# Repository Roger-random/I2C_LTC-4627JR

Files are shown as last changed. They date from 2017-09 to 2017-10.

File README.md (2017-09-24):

# I2C control of a Lite-On LTC4627-JR (4-digit 7-segment LED)

The goal of this project is to create a small module that interfaces a 4-digit 7-segment LED to an I2C bus.

The original motivation is to allow a Raspberry Pi to display a few hexadecimal numbers with minimal overhead. Send a few bytes over I2C and this module will handle the rest.

Parts:

* The LED unit is the Lite-On LTC4627-JR. 
It has some features in addition to the standard 4-digit 7-segment design:
1. This is actually an 8-segment LED because of the 7-segments for numerals plus a LED for the optional decimal point.
2. This is actually a 5-digit display because of a few additional symbols on the surface. It appears to have been designed for a clock display so there are three additional LEDs controlled as a "fifth digit":  Two LEDs for displaying the ":" in 12:00 and a third probably to designate AM/PM.

* The brains of this operation will be a PIC 16F18345

* Current-limiting resistors * 8, one for each of the segments.

* NPN transistors * 5, one for each of the digits.

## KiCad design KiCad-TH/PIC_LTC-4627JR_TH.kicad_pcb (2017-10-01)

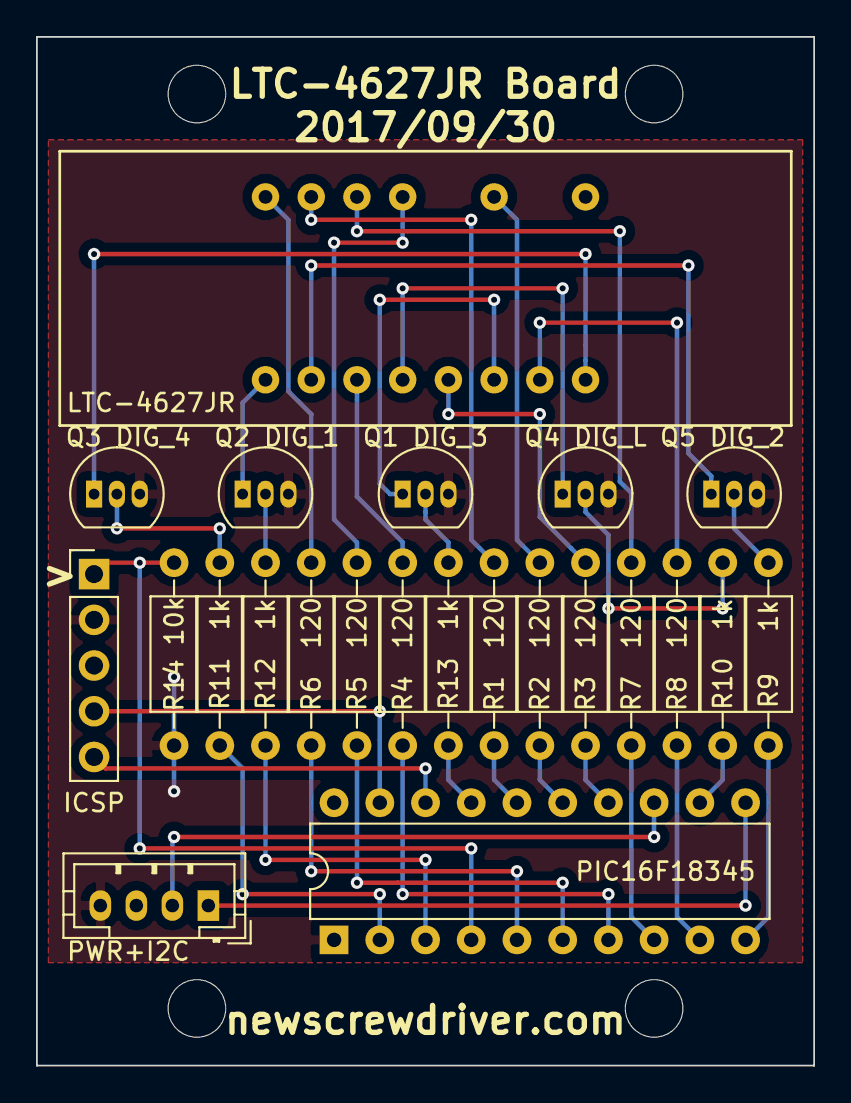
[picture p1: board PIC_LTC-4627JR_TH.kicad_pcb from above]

Board: 2 copper layers, 43.2 x 57.2 mm, 27 parts (0 on the bottom side), 38 nets.

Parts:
H1, H2, H3, H4: MountingHole_3.2mm_M3
ICSP: Conn_01x05_Male; Pin_Header_Straight_1x05_Pitch2.54mm
LTC-4627JR: LTC-4627JR
PIC16F18345: PIC16F18344-P; DIP-20_W7.62mm
PWR+I2C: Conn_01x04; JST_PH_B4B-PH-K_04x2.00mm_Straight
Q1 DIG_3, Q2 DIG_1, Q3 DIG_4, Q4 DIG_L, Q5 DIG_2: Q_NPN_EBC; TO-92_Inline_Narrow_Oval
R1  120, R2  120, R3  120, R4  120, R5  120, R6  120, R7  120, R8  120: 120; R_Axial_DIN0207_L6.3mm_D2.5mm_P10.16mm_Horizontal
R9   1k, R10  1k, R11  1k, R12  1k, R13  1k: 1k; R_Axial_DIN0207_L6.3mm_D2.5mm_P10.16mm_Horizontal
R14 10k: 10k; R_Axial_DIN0207_L6.3mm_D2.5mm_P10.16mm_Horizontal

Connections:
/DIG_1: LTC-4627JR.1, Q2 DIG_1.1
/DIG_2: LTC-4627JR.2, Q5 DIG_2.1
/DIG_3: LTC-4627JR.6, Q1 DIG_3.1
/DIG_4: LTC-4627JR.8, Q3 DIG_4.1
/DIG_L: LTC-4627JR.4, Q4 DIG_L.1
/I2CCL: PIC16F18345.11, PWR+I2C.1
/I2CDA: PIC16F18345.13, PWR+I2C.2
/ICSPCLK: ICSP.5, PIC16F18345.18
/ICSPDAT: ICSP.4, PIC16F18345.19
/VPP: ICSP.1, PIC16F18345.4, R14 10k.1
GND: ICSP.3, PIC16F18345.20, PWR+I2C.3
unnamed: LTC-4627JR.3, R4 120.1
unnamed: LTC-4627JR.5, R3 120.1
unnamed: LTC-4627JR.7, R8 120.1
unnamed: LTC-4627JR.11, R2 120.1
unnamed: LTC-4627JR.13, R5 120.1
unnamed: LTC-4627JR.14, R7 120.1
unnamed: LTC-4627JR.15, R1 120.1
unnamed: LTC-4627JR.16, R6 120.1
unnamed: Q1 DIG_3.2, R13 1k.1
unnamed: Q2 DIG_1.2, R12 1k.1
unnamed: Q3 DIG_4.2, R11 1k.1
unnamed: Q4 DIG_L.2, R10 1k.1
unnamed: Q5 DIG_2.2, R9 1k.1
unnamed: PIC16F18345.16, R1 120.2
unnamed: PIC16F18345.15, R2 120.2
unnamed: PIC16F18345.14, R3 120.2
unnamed: PIC16F18345.7, R4 120.2
unnamed: PIC16F18345.6, R5 120.2
unnamed: PIC16F18345.5, R6 120.2
unnamed: PIC16F18345.8, R7 120.2
unnamed: PIC16F18345.9, R8 120.2
unnamed: PIC16F18345.10, R9 1k.2
unnamed: PIC16F18345.12, R10 1k.2
unnamed: PIC16F18345.2, R11 1k.2
unnamed: PIC16F18345.3, R12 1k.2
unnamed: PIC16F18345.17, R13 1k.2
VCC: ICSP.2, PIC16F18345.1, PWR+I2C.4, Q1 DIG_3.3, Q2 DIG_1.3, Q3 DIG_4.3, Q4 DIG_L.3, Q5 DIG_2.3, R14 10k.2

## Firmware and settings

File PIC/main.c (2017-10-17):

/**
  Generated Main Source File

  Company:
    Microchip Technology Inc.

  File Name:
    main.c

  Summary:
    This is the main file generated using PIC10 / PIC12 / PIC16 / PIC18 MCUs 

  Description:
    This header file provides implementations for driver APIs for all modules selected in the GUI.
    Generation Information :
        Product Revision  :  PIC10 / PIC12 / PIC16 / PIC18 MCUs  - 1.45
        Device            :  PIC16F18345
        Driver Version    :  2.00
    The generated drivers are tested against the following:
        Compiler          :  XC8 1.35
        MPLAB             :  MPLAB X 3.40
*/

/*
    (c) 2016 Microchip Technology Inc. and its subsidiaries. You may use this
    software and any derivatives exclusively with Microchip products.

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
    IN NO EVENT WILL MICROCHIP BE LIABLE FOR ANY INDIRECT, SPECIAL, PUNITIVE,
    INCIDENTAL OR CONSEQUENTIAL LOSS, DAMAGE, COST OR EXPENSE OF ANY KIND
    WHATSOEVER RELATED TO THE SOFTWARE, HOWEVER CAUSED, EVEN IF MICROCHIP HAS
    BEEN ADVISED OF THE POSSIBILITY OR THE DAMAGES ARE FORESEEABLE. TO THE
    FULLEST EXTENT ALLOWED BY LAW, MICROCHIP'S TOTAL LIABILITY ON ALL CLAIMS IN
    ANY WAY RELATED TO THIS SOFTWARE WILL NOT EXCEED THE AMOUNT OF FEES, IF ANY,
    THAT YOU HAVE PAID DIRECTLY TO MICROCHIP FOR THIS SOFTWARE.

    MICROCHIP PROVIDES THIS SOFTWARE CONDITIONALLY UPON YOUR ACCEPTANCE OF THESE
    TERMS.
*/

#include "mcc_generated_files/mcc.h"

// Local variables

// Data received via I2C for what we should display
static uint8_t displayBuffer[DISPLAY_BUFFER_SIZE];

// Bit pattern to display each of the digits.
static uint8_t digitPatterns[] = {0xFF, 0xFF, 0xFF, 0xFF, 0xFF};

// Lookup table to translate numbers/letters into LED bit patterns
//
// The bit pattern mimics the one defined in the MAX7219 driver chip
//
//        A
//      -----
//     |     |
//   F |     | B            Byte
//     |  G  |              MSB                LSB
//      -----               7  6  5  4  3  2  1  0
//     |     |              DP A  B  C  D  E  F  G
//   E |     | C
//     |     |
//      -----
//        D       DP
//
// Since the LTC-4627JR LED module is a common-anode design, each of the bit
// controlling the segment is a cathode. Meaning the LED energizes when the
// bit is set to zero.
//  
//   0xFF = everything is dark.       0x00 = all segments are illuminated.

// Given a value in 0x0 - 0xF, decode into the bit pattern used to display that
// digit.
uint8_t decodeHex(uint8_t value)
{
    // 0000 0      0100 4      1000 8      1100 C
    // 0001 1      0101 5      1001 9      1101 D
    // 0010 2      0110 6      1010 A      1110 E
    // 0011 3      0111 7      1011 B      1111 F
    static uint8_t decoded[] = {
        0x81, // 0 = 1000 0001 
        0xCF, // 1 = 1100 1111
        0x92, // 2 = 1001 0010
        0x86, // 3 = 1000 0110
        0xCC, // 4 = 1100 1100
        0xA4, // 5 = 1010 0100
        0xA0, // 6 = 1010 0000
        0x8F, // 7 = 1000 1111
        0x80, // 8 = 1000 0000
        0x8C, // 9 = 1000 1100
        0x88, // A = 1000 1000
        0xE0, // B = 1110 0000
        0xB1, // C = 1011 0001
        0xC2, // D = 1100 0010
        0xB0, // E = 1011 0000
        0xB8  // F = 1011 1000
    };
    
    if (value <= 0xF)
    {
        return decoded[value];
    }
    else
    {
        return 0xFF; // Active low means 0xFF is dark.
    }
}

// Given a value in ASCII 0x00 - 0x7F, decode into the bit pattern used to
// display that ASCII character. Given the limited nature of a 7-segment
// LED only a few will return actual bit patterns. Most of them will return
// the pattern for space (0xFF))
uint8_t decodeASCII(uint8_t asciiValue)
{
    // Range of numbers 0-9
    if (asciiValue >= 0x30 && asciiValue <= 0x39)
    {
        // Subtracting the ascii value of '0' returns hex index for decodeHex
        return decodeHex(asciiValue - 0x30);
    }
    // Range of uppercase letters A-F
    if (asciiValue >= 0x41 && asciiValue <= 0x46)
    {
        // Subtracting the ascii of 'A' plus 10 returns hex index for decodeHex.
        return decodeHex(asciiValue - 0x41 + 10);
    }
    // Range of lowercase letters A-F
    if (asciiValue >= 0x61 && asciiValue <= 0x66)
    {
        // Subtracting the ascii of 'a' plus 10 returns hex index for decodeHex.
        return decodeHex(asciiValue - 0x61 + 10);
    }
    return 0xFF; // Blank space
}

// Called by a timer ISR to illuminate another digit in the display.
void nextDigit(void)
{
    static uint8_t digit = 0;

    switch(digit)
    {
        case 0:
            DIG_L_SetLow();
            LATC = digitPatterns[0];
            DIG_1_SetHigh();
            digit = 1;
            break;
        case 1:
            DIG_1_SetLow();
            LATC = digitPatterns[1];
            DIG_2_SetHigh();
            digit = 2;
            break;
        case 2:
            DIG_2_SetLow();
            LATC = digitPatterns[2];
            DIG_3_SetHigh();
            digit = 3;
            break;
        case 3:
            DIG_3_SetLow();
            LATC = digitPatterns[3];
            DIG_4_SetHigh();
            digit = 4;
            break;
        case 4:
            DIG_4_SetLow();
            LATC = digitPatterns[4];
            DIG_L_SetHigh();
            digit = 0;
            break;
        default:
            DIG_1_SetLow();
            DIG_2_SetLow();
            DIG_3_SetLow();
            DIG_4_SetLow();
            DIG_L_SetLow();
            LATC = 0x0;
            digit = 0;
            break;
    }
}

/*
                         Main application
 */
void main(void)
{
    size_t dataIndex = 0;

    // initialize the device
    SYSTEM_Initialize();

    // When using interrupts, you need to set the Global and Peripheral Interrupt Enable bits
    // Use the following macros to:

    // Enable the Global Interrupts
    INTERRUPT_GlobalInterruptEnable();

    // Enable the Peripheral Interrupts
    INTERRUPT_PeripheralInterruptEnable();

    // Disable the Global Interrupts
    //INTERRUPT_GlobalInterruptDisable();

    // Disable the Peripheral Interrupts
    //INTERRUPT_PeripheralInterruptDisable();

    digitPatterns[0] = 0xC9; // Nonstandard "II" in a single digit
    digitPatterns[1] = decodeASCII('C');
    digitPatterns[2] = decodeASCII('4');
    digitPatterns[3] = decodeASCII('2');
    digitPatterns[4] = 0xFF;
    
    while (1)
    {
        if(I2C1_DataAvailable())
        {
            I2C1_CopyDisplayBuffer(displayBuffer);

            // Digit 5 are dark unless specifically illuminated
            digitPatterns[4] = 0xFF;

            dataIndex = 0;
            for (size_t digit = 0; digit < 4; digit++)
            {
                digitPatterns[digit] = decodeASCII(displayBuffer[dataIndex]);
                dataIndex++;
                if (displayBuffer[dataIndex]=='.')
                {
                    // Light up the decimal point
                    digitPatterns[digit] = digitPatterns[digit] & 0x7F;
                    dataIndex++;
                }
                if (digit==1 && displayBuffer[dataIndex]==':')
                {
                    // Light up the colon
                    digitPatterns[4] = digitPatterns[4] & 0x9F;
                    dataIndex++;
                }
                if (digit==2 && (displayBuffer[dataIndex]=='\'') || (displayBuffer[dataIndex]=='`'))
                {
                    // Light up the upper dot thingie
                    digitPatterns[4] = digitPatterns[4] & 0xEF;
                    dataIndex++;
                }
            }
        }
    }
}
/**
 End of File
*/

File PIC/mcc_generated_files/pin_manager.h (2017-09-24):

/**
  @Generated Pin Manager Header File

  @Company:
    Microchip Technology Inc.

  @File Name:
    pin_manager.h

  @Summary:
    This is the Pin Manager file generated using MPLAB(c) Code Configurator

  @Description:
    This header file provides implementations for pin APIs for all pins selected in the GUI.
    Generation Information :
        Product Revision  :  MPLAB(c) Code Configurator - 4.26
        Device            :  PIC16F18345
        Version           :  1.01
    The generated drivers are tested against the following:
        Compiler          :  XC8 1.35
        MPLAB             :  MPLAB X 3.40

    Copyright (c) 2013 - 2015 released Microchip Technology Inc.  All rights reserved.

    Microchip licenses to you the right to use, modify, copy and distribute
    Software only when embedded on a Microchip microcontroller or digital signal
    controller that is integrated into your product or third party product
    (pursuant to the sublicense terms in the accompanying license agreement).

    You should refer to the license agreement accompanying this Software for
    additional information regarding your rights and obligations.

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
*/


#ifndef PIN_MANAGER_H
#define PIN_MANAGER_H

#define INPUT   1
#define OUTPUT  0

#define HIGH    1
#define LOW     0

#define ANALOG      1
#define DIGITAL     0

#define PULL_UP_ENABLED      1
#define PULL_UP_DISABLED     0

// get/set DIG_3 aliases
#define DIG_3_TRIS               TRISAbits.TRISA2
#define DIG_3_LAT                LATAbits.LATA2
#define DIG_3_PORT               PORTAbits.RA2
#define DIG_3_WPU                WPUAbits.WPUA2
#define DIG_3_OD                ODCONAbits.ODCA2
#define DIG_3_ANS                ANSELAbits.ANSA2
#define DIG_3_SetHigh()            do { LATAbits.LATA2 = 1; } while(0)
#define DIG_3_SetLow()             do { LATAbits.LATA2 = 0; } while(0)
#define DIG_3_Toggle()             do { LATAbits.LATA2 = ~LATAbits.LATA2; } while(0)
#define DIG_3_GetValue()           PORTAbits.RA2
#define DIG_3_SetDigitalInput()    do { TRISAbits.TRISA2 = 1; } while(0)
#define DIG_3_SetDigitalOutput()   do { TRISAbits.TRISA2 = 0; } while(0)
#define DIG_3_SetPullup()      do { WPUAbits.WPUA2 = 1; } while(0)
#define DIG_3_ResetPullup()    do { WPUAbits.WPUA2 = 0; } while(0)
#define DIG_3_SetPushPull()    do { ODCONAbits.ODCA2 = 1; } while(0)
#define DIG_3_SetOpenDrain()   do { ODCONAbits.ODCA2 = 0; } while(0)
#define DIG_3_SetAnalogMode()  do { ANSELAbits.ANSA2 = 1; } while(0)
#define DIG_3_SetDigitalMode() do { ANSELAbits.ANSA2 = 0; } while(0)

// get/set DIG_1 aliases
#define DIG_1_TRIS               TRISAbits.TRISA4
#define DIG_1_LAT                LATAbits.LATA4
#define DIG_1_PORT               PORTAbits.RA4
#define DIG_1_WPU                WPUAbits.WPUA4
#define DIG_1_OD                ODCONAbits.ODCA4
#define DIG_1_ANS                ANSELAbits.ANSA4
#define DIG_1_SetHigh()            do { LATAbits.LATA4 = 1; } while(0)
#define DIG_1_SetLow()             do { LATAbits.LATA4 = 0; } while(0)
#define DIG_1_Toggle()             do { LATAbits.LATA4 = ~LATAbits.LATA4; } while(0)
#define DIG_1_GetValue()           PORTAbits.RA4
#define DIG_1_SetDigitalInput()    do { TRISAbits.TRISA4 = 1; } while(0)
#define DIG_1_SetDigitalOutput()   do { TRISAbits.TRISA4 = 0; } while(0)
#define DIG_1_SetPullup()      do { WPUAbits.WPUA4 = 1; } while(0)
#define DIG_1_ResetPullup()    do { WPUAbits.WPUA4 = 0; } while(0)
#define DIG_1_SetPushPull()    do { ODCONAbits.ODCA4 = 1; } while(0)
#define DIG_1_SetOpenDrain()   do { ODCONAbits.ODCA4 = 0; } while(0)
#define DIG_1_SetAnalogMode()  do { ANSELAbits.ANSA4 = 1; } while(0)
#define DIG_1_SetDigitalMode() do { ANSELAbits.ANSA4 = 0; } while(0)

// get/set DIG_4 aliases
#define DIG_4_TRIS               TRISAbits.TRISA5
#define DIG_4_LAT                LATAbits.LATA5
#define DIG_4_PORT               PORTAbits.RA5
#define DIG_4_WPU                WPUAbits.WPUA5
#define DIG_4_OD                ODCONAbits.ODCA5
#define DIG_4_ANS                ANSELAbits.ANSA5
#define DIG_4_SetHigh()            do { LATAbits.LATA5 = 1; } while(0)
#define DIG_4_SetLow()             do { LATAbits.LATA5 = 0; } while(0)
#define DIG_4_Toggle()             do { LATAbits.LATA5 = ~LATAbits.LATA5; } while(0)
#define DIG_4_GetValue()           PORTAbits.RA5
#define DIG_4_SetDigitalInput()    do { TRISAbits.TRISA5 = 1; } while(0)
#define DIG_4_SetDigitalOutput()   do { TRISAbits.TRISA5 = 0; } while(0)
#define DIG_4_SetPullup()      do { WPUAbits.WPUA5 = 1; } while(0)
#define DIG_4_ResetPullup()    do { WPUAbits.WPUA5 = 0; } while(0)
#define DIG_4_SetPushPull()    do { ODCONAbits.ODCA5 = 1; } while(0)
#define DIG_4_SetOpenDrain()   do { ODCONAbits.ODCA5 = 0; } while(0)
#define DIG_4_SetAnalogMode()  do { ANSELAbits.ANSA5 = 1; } while(0)
#define DIG_4_SetDigitalMode() do { ANSELAbits.ANSA5 = 0; } while(0)

// get/set RB4 procedures
#define RB4_SetHigh()    do { LATBbits.LATB4 = 1; } while(0)
#define RB4_SetLow()   do { LATBbits.LATB4 = 0; } while(0)
#define RB4_Toggle()   do { LATBbits.LATB4 = ~LATBbits.LATB4; } while(0)
#define RB4_GetValue()         PORTBbits.RB4
#define RB4_SetDigitalInput()   do { TRISBbits.TRISB4 = 1; } while(0)
#define RB4_SetDigitalOutput()  do { TRISBbits.TRISB4 = 0; } while(0)
#define RB4_SetPullup()     do { WPUBbits.WPUB4 = 1; } while(0)
#define RB4_ResetPullup()   do { WPUBbits.WPUB4 = 0; } while(0)
#define RB4_SetAnalogMode() do { ANSELBbits.ANSB4 = 1; } while(0)
#define RB4_SetDigitalMode()do { ANSELBbits.ANSB4 = 0; } while(0)

// get/set DIG_L aliases
#define DIG_L_TRIS               TRISBbits.TRISB5
#define DIG_L_LAT                LATBbits.LATB5
#define DIG_L_PORT               PORTBbits.RB5
#define DIG_L_WPU                WPUBbits.WPUB5
#define DIG_L_OD                ODCONBbits.ODCB5
#define DIG_L_ANS                ANSELBbits.ANSB5
#define DIG_L_SetHigh()            do { LATBbits.LATB5 = 1; } while(0)
#define DIG_L_SetLow()             do { LATBbits.LATB5 = 0; } while(0)
#define DIG_L_Toggle()             do { LATBbits.LATB5 = ~LATBbits.LATB5; } while(0)
#define DIG_L_GetValue()           PORTBbits.RB5
#define DIG_L_SetDigitalInput()    do { TRISBbits.TRISB5 = 1; } while(0)
#define DIG_L_SetDigitalOutput()   do { TRISBbits.TRISB5 = 0; } while(0)
#define DIG_L_SetPullup()      do { WPUBbits.WPUB5 = 1; } while(0)
#define DIG_L_ResetPullup()    do { WPUBbits.WPUB5 = 0; } while(0)
#define DIG_L_SetPushPull()    do { ODCONBbits.ODCB5 = 1; } while(0)
#define DIG_L_SetOpenDrain()   do { ODCONBbits.ODCB5 = 0; } while(0)
#define DIG_L_SetAnalogMode()  do { ANSELBbits.ANSB5 = 1; } while(0)
#define DIG_L_SetDigitalMode() do { ANSELBbits.ANSB5 = 0; } while(0)
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

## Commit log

2017-09-24 Add MSSP1 for I2C (SDA1 on B4, SCL1 on B6)
2017-09-24 Add TMR0 at period of 2 milliseconds
2017-09-28 New KiCad project
    [PIC_LTC-4627JR_TH.kicad_pcb, PIC_LTC-4627JR_TH.sch]
2017-09-28 Add KiCad .gitignore file
2017-09-28 New schematic
    [PIC_LTC-4627JR_TH.sch]
2017-09-28 Stock components
    [PIC_LTC-4627JR_TH.sch]
2017-09-28 Wire up stock components
    [PIC_LTC-4627JR_TH.sch]
2017-09-28 Add and wire custom LTC-4627JR to complete schematic
    [PIC_LTC-4627JR_TH.sch]
2017-09-28 Direct connect pins for segments from PIC to LED
    [PIC_LTC-4627JR_TH.sch]
2017-09-28 Transistors now in a single vertical column
    [PIC_LTC-4627JR_TH.sch]
2017-09-28 WIP: Routing is a mess, not done yet.
    [PIC_LTC-4627JR_TH.kicad_pcb]
2017-09-28 LTC-4627JR footprint
    [_saved_PIC_LTC-4627JR_TH.sch]
2017-09-28 Deleted all the tracks to start again.
    [PIC_LTC-4627JR_TH.kicad_pcb, PIC_LTC-4627JR_TH.sch, _saved_PIC_LTC-4627JR_TH.sch]
2017-09-28 Round 2: Not pretty, but at least it's all connected.
    [PIC_LTC-4627JR_TH.kicad_pcb]
2017-09-28 Added edge, which highlighted lack of mounting holes.
    [PIC_LTC-4627JR_TH.kicad_pcb]
2017-09-28 PCB Routing Round #3: Getting better, still room for improvement.
    [PIC_LTC-4627JR_TH.kicad_pcb]
2017-09-29 PCB Routing Round #4: Submit Candidate 1
    [PIC_LTC-4627JR_TH.kicad_pcb]
2017-09-30 Switch from drawn hole to actual hole component
    [PIC_LTC-4627JR_TH.kicad_pcb]
2017-09-30 VCC and GND now fill zones instead of traces
    [PIC_LTC-4627JR_TH.kicad_pcb]
2017-09-30 Erase PCB to start from scratch
    [PIC_LTC-4627JR_TH.kicad_pcb]
2017-09-30 Fix transistor footprint and add 1kOhm resistor between PIC and transistor base
    [PIC_LTC-4627JR_TH.sch]
2017-09-30 OSH Park Rules
    [PIC_LTC-4627JR_TH.kicad_pcb]
2017-09-30 OSH Park Layers Setup
    [PIC_LTC-4627JR_TH.kicad_pcb]
2017-09-30 PCB Routing Round 5 Begins
    [PIC_LTC-4627JR_TH.kicad_pcb]
2017-09-30 PCB #5 Looking Good Still Needs Polish
    [PIC_LTC-4627JR_TH.kicad_pcb]
2017-09-30 Add pull-up resistor to Vpp as per PICkit 3 manual
    [PIC_LTC-4627JR_TH.sch]
2017-10-01 PCB#5 now with Vpp pull-up resistor
    [PIC_LTC-4627JR_TH.kicad_pcb]
2017-10-01 Front SilkS
    [PIC_LTC-4627JR_TH.kicad_pcb]
2017-10-01 Edge cut, M3 mounting holes, Back SilkS
    [PIC_LTC-4627JR_TH.kicad_pcb]
2017-10-17 Example to display reading from Si7021 on LTC-4627JR via I2C
2017-10-17 Temperature now updates every 0.1 seconds (10 updates per second)
